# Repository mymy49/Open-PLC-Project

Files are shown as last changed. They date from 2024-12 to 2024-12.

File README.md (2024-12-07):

# Open-PLC-Project
yss OS를 사용한 오픈 소스/회로 PLC 프로젝트입니다.

중국의 [LCSC ELECTRONICS](https://www.lcsc.com/)에서 '전자 부품' + 'PCB' + 'SMT' 주문을 한번에 진행할 수 있는 자료를 모두 오픈할 계획입니다. 
누구나 PCB를 주문해서 거의 완성된 상태로 받아볼 수 있도록 할 계획입니다.
보드의 전체 기능이 yss OS 기반에서 제어 가능한 소스코드를 다운로드하여 필요한 동작을 구현하는 프로젝트입니다.

# 사용 프로그램
* 회로도/PCB : Kicad (<https://www.kicad.org/>)
* Compiler + IDE : gcc + Crossworks for ARM (<https://www.rowley.co.uk/arm/index.htm>)
* Office : Libreoffice (<https://www.libreoffice.org/>)

# Base Board
Base Board는 기본적인 소량의 디지털 I/O, 릴레이, AIN, AOUT을 갖출 계획입니다. 
부족한 기능은 외부에 보드를 추가해 CAN으로 서로 통신하며 기능을 보완하는 것을 계획하고 있습니다.

케이스 : <https://ko.aliexpress.com/item/1005003779239575.html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>

## 단자 구성
케이스는 총 40핀으로 구성되어 있습니다. 
핀맵은 아래와 같이 구성됩니다.

1. [전원] +8~24V (프리볼트)
2. [전원] GND
3. [통신] CANL
4. [통신] CANH

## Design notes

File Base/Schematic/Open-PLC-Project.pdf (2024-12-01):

Open-PLC-Project

페이지 1

# | Reference | Value | Qty | DNP | Manufacturer | 설명

1 | C1,C2 | 0603N120J500 | 2 | | WALSIN | 15pF ±5% 50V NP0
2 | C3 | 0603X475K100 | 1 | | WALSIN | 4.7uF ±10% 10V X5R
3 | C4,C5,C6,C7,C8,C12,C13,C15 | 0603B104K500 | 8 | | WALSIN | 100nF ±10% 50V X7R
4 | C9,C10,C11 | 1210B225K101 | 3 | | WALSIN | 2.2uF ±10% 100V X7R
5 | C14 | 1206B226K100 | 1 | | WALSIN | 22uF ±10% 10V X7R
6 | L1 | SWPA5040S150MT | 1 | | Sunlord | 15uH ±20% 0.086 Ohm 2.0A Isat Shielded
7 | R1 | WR06X1002FTL | 1 | | WALSIN | 10 kOhm 1% 1/10W
8 | R2 | WR06X0000JTL | 1 | DNP | WALSIN | 0 Ohm 5% 1/10W
9 | R3 | WR06X4123FTL | 1 | | WALSIN | 412 kOhm ±1% 1/10W
10 | R4 | WR06X2003FTL | 1 | | WALSIN | 200 kOhm ±1% 1/10W
11 | R5 | WR06X5102FTL | 1 | | WALSIN | 51kOhm ±1% 1/10W
12 | R6 | WR06X2212FTL | 1 | | WALSIN | 22.1kOhm ±1% 1/10W
13 | U1 | STM32F446RET6 | 1 | | ST | ARM Cortex-M4 512kB Flash 128kB RAM 180MHz
14 | U2 | TPS560430XDBV | 1 | | TI | SIMPLE SWITCHER 4V to 36V, 600mA Synchronous Step-Down Converter
15 | U3 | CA-IS3052CW | 1 | | TI | Isolated CAN Transceiver
16 | X1 | 1532H4-12000JWPDTSNL | 1 | | HCI | 12MHz 15pF -40~85℃

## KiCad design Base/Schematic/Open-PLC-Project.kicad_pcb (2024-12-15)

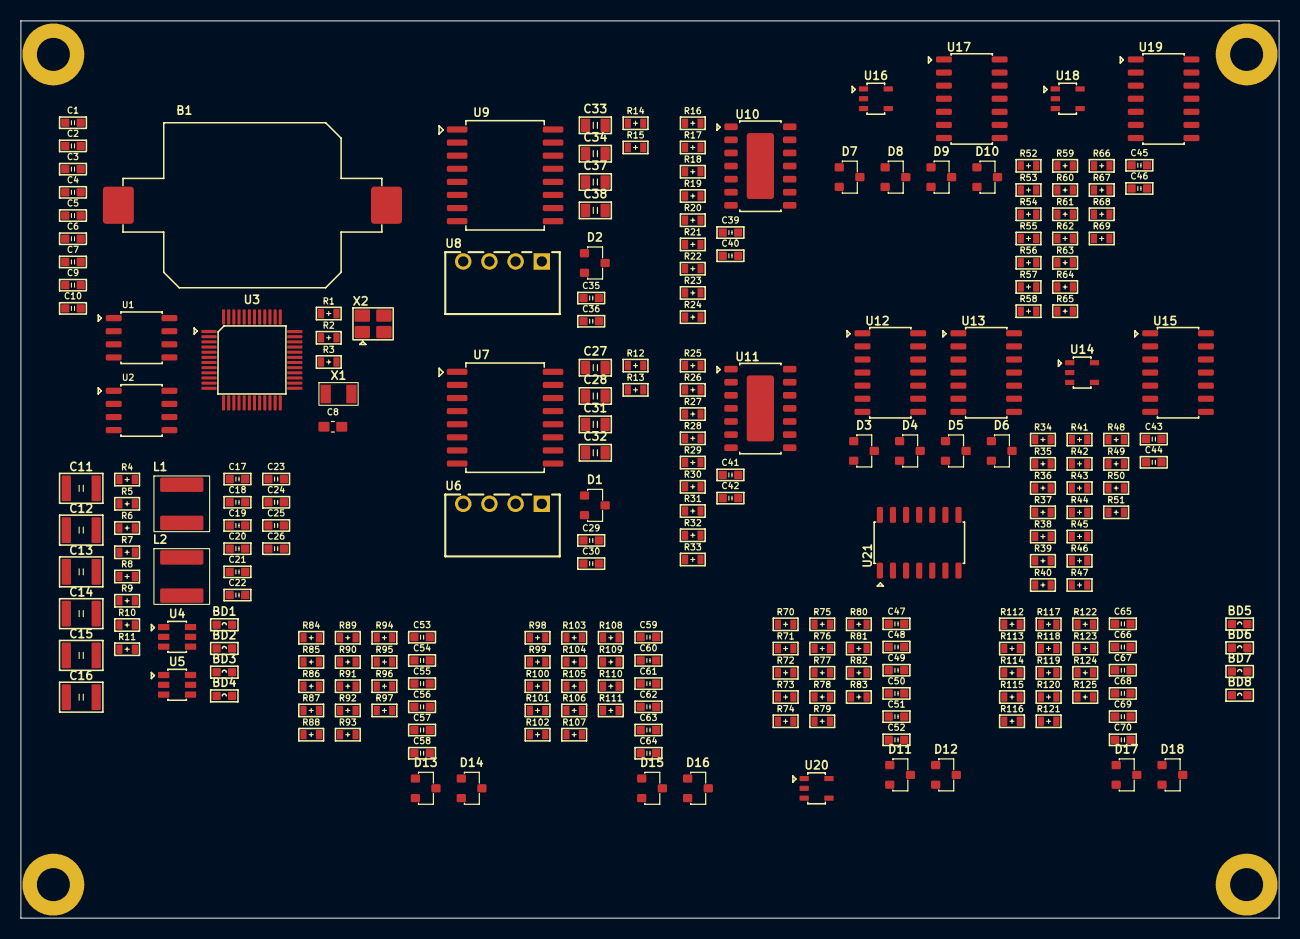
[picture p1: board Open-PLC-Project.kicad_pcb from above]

Board: 2 copper layers, 122.0 x 87.0 mm, 251 parts (0 on the bottom side), 140 nets, no tracks yet.

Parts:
B1: GT-CR1632-1Au
BD1, BD2, BD3, BD4, BD5, BD6, BD7, BD8: BLM18KG121TN1D; 0603
C1, C4, C7, C9, C10, C17, C18, C19, C20, C21, C22, C29, C30, C35, C36, C40, C42, C43, C44, C45, C46, C47, C51, C52, C53, C57, C58, C59, C63, C64, C65, C69, C70: 0603B104K500; 0603
C2, C3, C5, C6: 0603N120J500; 0603
C8: 0603X225K100; C_0603_1608Metric_Pad1.08x0.95mm_HandSolder
C11, C12, C13, C14, C15, C16: 1210B225K101; 1210
C23, C24, C25, C26: 0603X106K100; 0603
C27, C28, C33, C34: 1206B225K500; 0805
C31, C32, C37, C38: 0805B475K160; 0805
C39, C41, C48, C49, C50, C54, C55, C56, C60, C61, C62, C66, C67, C68: 0603B101K500; 0603
D1: NUP2105LT1G; SOT23
D2: PSM712-ES; SOT23
D3, D4, D5, D6, D7, D8, D9, D10, D11, D12, D13, D14, D15, D16, D17, D18: KDS226; SOT23
H1, H2, H3, H4: HOLE-PAD-7.0-3.2; Hole_7_0_3_2
L1, L2: SWPA5040S150MT; SWPA5040S
R1, R2, R23, R32, R34, R36, R37, R38, R39, R40, R41, R42, R43, R44, R45, R46, R47, R52, R54, R55, R56, R57, R58, R59, R60, R61, R62, R63, R64, R65: WR06X4701FTL; 0603
R3: WR06W3R30FTL; 0603
R4, R6: WR06X4123FTL; 0603
R5, R7: WR06X2003FTL; 0603
R8: WR06X8872FTL; 0603
R9, R11: WR06X2212FTL; 0603
R10: WR06X5102FTL; 0603
R12, R13, R14, R15: WR06X0000JTL; 0603
R16, R17, R18, R19, R20, R21, R22, R25, R26, R27, R28, R29, R30, R31, R48, R49, R50, R51, R66, R67, R68, R69, R70, R71, R72, R73, R78, R79, R80, R81, R84, R85, R86, R87, R92, R93, R94, R95, R98, R99, R100, R101, R106, R107, R108, R109, R112, R113, R114, R115, R120, R121, R122, R123: WR06X1002FTL; 0603
R24, R33: WR06X1201FTL; 0603
R35, R53: WR06X4700FTL; 0603
R74, R75, R76, R77, R88, R89, R90, R91, R102, R103, R104, R105, R116, R117, R118, R119: WR06X3302FTL; 0603
R82, R83, R96, R97, R110, R111, R124, R125: WR06X1001FTL; 0603
U1: MB85RC16PNF-G-JNE; SOIC-8
U2: SL1307ZN+T; SOIC-8
U3: M433LE8AE; LQFP48
U4, U5: TPS560430XDBV; DBV0006A
U6, U8: B0505S-1W; BXXS-1W
U7: CA-IS3052CW; SOIC-16-WB
U9: CA-IS3082WX; SOIC-16-WB
U10, U11: BTS5200-4EKA; PG-DSO-14-48-EP
U12, U13: LM239DR2G; SOIC-14
U14, U16, U18, U20: LMV321-TR; SOT-23-5L
U15, U17, U19, U21: TP2584-SR; SOIC-14
X1: XKXGI-SUA-32.768K; SMD_3215_2Pin
X2: 1532H4-12000JWPDTSNL; CRSTAL_SMD_3225-4Pin

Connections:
+3.3V: BD5.2, BD7.2, C1.2, C9.2, C10.2, D11.2 (C1), D12.2 (C1), D13.2 (C1), D14.2 (C1), D15.2 (C1), D16.2 (C1), D17.2 (C1), D18.2 (C1), R1.2, R2.2, R3.2, R44.2, R45.2, R46.2, R47.2, R62.2, R63.2, R64.2, R65.2, U1.8 (VCC), U2.8 (VCC), U3.23 (VDD), U3.39 (VDD), U7.1 (VCC1), U9.1 (VCC1)
+5V: C21.2, C23.2, C25.2, C27.2, C28.2, C29.2, C33.2, C34.2, C35.2, L1.2, R8.1, U6.2 (Vin), U8.2 (Vin)
+5V_485: C36.2, C37.2, C38.2, U8.4 (Vout), U9.16 (VCC2)
+5V_CAN: C30.2, C31.2, C32.2, U6.4 (Vout), U7.16 (VCC2)
/AIN1/AIN_OUT+: C49.1, C51.2, D11.3 (A1C2), R79.2, R82.2
/AIN1/AIN_OUT-: C50.1, C52.2, D12.3 (A1C2), R81.2, R83.2
/AIN1/REF: R78.2, R80.2, U14.3 (-), U14.4 (OUT)
/AIN2/AIN_OUT+: C55.1, C57.2, D13.3 (A1C2), R93.2, R96.2
/AIN2/AIN_OUT-: C56.1, C58.2, D14.3 (A1C2), R95.2, R97.2
/AIN2/REF: R92.2, R94.2, U16.3 (-), U16.4 (OUT)
/AIN3/AIN_OUT+: C61.1, C63.2, D15.3 (A1C2), R107.2, R110.2
/AIN3/AIN_OUT-: C62.1, C64.2, D16.3 (A1C2), R109.2, R111.2
/AIN3/REF: R106.2, R108.2, U18.3 (-), U18.4 (OUT)
/AIN4/AIN_OUT+: C67.1, C69.2, D17.3 (A1C2), R121.2, R124.2
/AIN4/AIN_OUT-: C68.1, C70.2, D18.3 (A1C2), R123.2, R125.2
/AIN4/REF: R120.2, R122.2, U20.3 (-), U20.4 (OUT)
/CAN/CANH: D1.1 (A2), R12.2
/CAN/CANL: D1.2 (C1), R13.2
/DIN1/VREF: C43.2, R34.2, R35.2, U12.6 (-), U13.4 (-), U13.8 (-), U13.10 (-)
/DIN2/VREF: C45.2, R52.2, R53.2, U12.4 (-), U12.8 (-), U12.10 (-), U13.6 (-)
/DOUT1/IS: C39.2, R23.1
/DOUT2/IS: C41.2, R32.1
/MCU/OSC_IN: C5.2, U3.13 (PF3/XT1_IN), X2.1
/MCU/OSC_OUT: C6.2, U3.14 (PF2/XT1_OUT), X2.3
/MCU/SCL: R2.1, U1.6 (SCL), U2.6 (SCL)
/MCU/SDA: R1.1, U1.5 (SDA), U2.5 (SDA)
/MCU/X1: C3.2, U2.1 (X1), X1.2
/MCU/X2: C2.2, U2.2 (X2), X1.1
/RS485/A: D2.1 (A2), R14.2
/RS485/B: D2.2 (C1), R15.2
AGND: BD4.2, BD6.1, C47.1, C51.1, C52.1, C53.1, C57.1, C58.1, C59.1, C63.1, C64.1, C65.1, C69.1, C70.1, D11.1 (A2), D12.1 (A2), D13.1 (A2), D14.1 (A2), D15.1 (A2), D16.1 (A2), D17.1 (A2), D18.1 (A2), R71.2, R85.2, R99.2, R113.2, U3.46 (AVSS), U14.2 (VSS), U15.11 (GND), U16.2 (VSS), U17.11 (GND), U18.2 (VSS), U19.11 (GND), U20.2 (VSS), U21.11 (GND)
A_+3.3V: BD5.1, R70.1, R84.1, R98.1, R112.1, U14.5 (VDD), U16.5 (VDD), U18.5 (VDD), U20.5 (VDD)
A_V_SUPPLY: BD3.2, U15.4 (VCC), U17.4 (VCC), U19.4 (VCC), U21.4 (VCC)
GND: B1.2 (-), BD6.2, BD8.2, C1.1, C2.1, C3.1, C4.1, C5.1, C6.1, C7.1, C8.1, C9.1, C10.1, C39.1, C41.1, U1.4 (VSS), U2.4 (VSS), U3.37 (VSS), U7.2 (GND1), U7.8 (GND1), U9.2 (GND1), U9.7 (GND1), U9.8 (GND1)
GND_485: C36.1, C37.1, C38.1, U8.3 (0V), U9.9 (GND2), U9.10 (GND2), U9.15 (GND2)
GND_CAN: C30.1, C31.1, C32.1, D1.3 (A1C2), D2.3 (A1C2), U6.3 (0V), U7.9 (GND2), U7.10 (GND2), U7.15 (GND2)
unnamed: B1.1 (+), C4.2, U2.3 (VBAT)
unnamed: BD7.1, C22.2, C24.2, C26.2, L2.2, R10.2
unnamed: D3.3 (A1C2), R36.2, R40.1
unnamed: D4.3 (A1C2), R37.2, R41.1
unnamed: D5.3 (A1C2), R38.2, R42.1
unnamed: D6.3 (A1C2), R39.2, R43.1
unnamed: D7.3 (A1C2), R54.2, R58.1
unnamed: D8.3 (A1C2), R55.2, R59.1
unnamed: D9.3 (A1C2), R56.2, R60.1
unnamed: D10.3 (A1C2), R57.2, R61.1
unnamed: C7.2, R3.1, U3.45 (AVDD)
unnamed: C8.2, U3.38 (LDO_CAP)
unnamed: C19.2, U4.1 (CB)
unnamed: R4.1, R5.2, U4.4 (EN)
unnamed: R8.2, R9.2, U4.3 (FB)
unnamed: C19.1, L1.1, U4.6 (SW)
unnamed: BD1.2, C11.2, C13.2, C15.2, C17.2, R4.2, U4.5 (VIN)
unnamed: C20.2, U5.1 (CB)
unnamed: R6.1, R7.2, U5.4 (EN)
unnamed: R10.1, R11.2, U5.3 (FB)
unnamed: C20.1, L2.1, U5.6 (SW)
unnamed: BD2.2, C12.2, C14.2, C16.2, C18.2, R6.2, U5.5 (VIN)
unnamed: R12.1, U7.13 (CANH)
unnamed: R13.1, U7.12 (CANL)
unnamed: R14.1, U9.12 (A)
unnamed: R15.1, U9.13 (B)
unnamed: R20.2, U10.10 (DEN)
unnamed: R21.2, U10.5 (DSEL0)
unnamed: R22.2, U10.4 (DSEL1)
unnamed: R16.2, U10.7 (IN0)
unnamed: R17.2, U10.6 (IN1)
unnamed: R18.2, U10.8 (IN2)
unnamed: R19.2, U10.9 (IN3)
unnamed: R23.2, R24.2, U10.12 (IS)
unnamed: R29.2, U11.10 (DEN)
unnamed: R30.2, U11.5 (DSEL0)
unnamed: R31.2, U11.4 (DSEL1)
unnamed: R25.2, U11.7 (IN0)
unnamed: R26.2, U11.6 (IN1)
unnamed: R27.2, U11.8 (IN2)
unnamed: R28.2, U11.9 (IN3)
unnamed: R32.2, R33.2, U11.12 (IS)
unnamed: R40.2, U12.7 (+)
unnamed: R44.1, R48.1, U12.1 (OUT)
unnamed: R59.2, U12.5 (+)
unnamed: R63.1, R67.1, U12.2 (OUT)
unnamed: R60.2, U12.9 (+)
unnamed: R64.1, R68.1, U12.14 (OUT)
unnamed: R61.2, U12.11 (+)
unnamed: R65.1, R69.1, U12.13 (OUT)
unnamed: R58.2, U13.7 (+)
unnamed: R62.1, R66.1, U13.1 (OUT)
unnamed: R41.2, U13.5 (+)
unnamed: R45.1, R49.1, U13.2 (OUT)
unnamed: R42.2, U13.9 (+)
unnamed: R46.1, R50.1, U13.14 (OUT)
unnamed: R43.2, U13.11 (+)
unnamed: R47.1, R51.1, U13.13 (OUT)
unnamed: C47.2, R70.2, R71.1, U14.1 (+)
unnamed: C48.1, R72.2, U15.3 (+)
unnamed: R74.1, R77.1, U15.1 (OUT), U15.2 (-)
unnamed: C48.2, R73.2, U15.5 (+)
unnamed: R75.1, R76.1, U15.6 (-), U15.7 (OUT)
unnamed: R74.2, R78.1, U15.10 (+)
unnamed: C49.2, R75.2, R79.1, U15.9 (-)
unnamed: R82.1, U15.8 (OUT)
unnamed: R76.2, R80.1, U15.12 (+)
unnamed: C50.2, R77.2, R81.1, U15.13 (-)
unnamed: R83.1, U15.14 (OUT)
unnamed: C53.2, R84.2, R85.1, U16.1 (+)
unnamed: C54.1, R86.2, U17.3 (+)
unnamed: R88.1, R91.1, U17.1 (OUT), U17.2 (-)
unnamed: C54.2, R87.2, U17.5 (+)
unnamed: R89.1, R90.1, U17.6 (-), U17.7 (OUT)
unnamed: R88.2, R92.1, U17.10 (+)
unnamed: C55.2, R89.2, R93.1, U17.9 (-)
unnamed: R96.1, U17.8 (OUT)
unnamed: R90.2, R94.1, U17.12 (+)
unnamed: C56.2, R91.2, R95.1, U17.13 (-)
unnamed: R97.1, U17.14 (OUT)
unnamed: C59.2, R98.2, R99.1, U18.1 (+)
unnamed: C60.1, R100.2, U19.3 (+)
unnamed: R102.1, R105.1, U19.1 (OUT), U19.2 (-)
unnamed: C60.2, R101.2, U19.5 (+)
unnamed: R103.1, R104.1, U19.6 (-), U19.7 (OUT)
unnamed: R102.2, R106.1, U19.10 (+)
unnamed: C61.2, R103.2, R107.1, U19.9 (-)
unnamed: R110.1, U19.8 (OUT)
unnamed: R104.2, R108.1, U19.12 (+)
unnamed: C62.2, R105.2, R109.1, U19.13 (-)
unnamed: R111.1, U19.14 (OUT)
unnamed: C65.2, R112.2, R113.1, U20.1 (+)
unnamed: C66.1, R114.2, U21.3 (+)
unnamed: R116.1, R119.1, U21.1 (OUT), U21.2 (-)
unnamed: C66.2, R115.2, U21.5 (+)
unnamed: R117.1, R118.1, U21.6 (-), U21.7 (OUT)
unnamed: R116.2, R120.1, U21.10 (+)
unnamed: C67.2, R117.2, R121.1, U21.9 (-)
unnamed: R124.1, U21.8 (OUT)
unnamed: R118.2, R122.1, U21.12 (+)
unnamed: C68.2, R119.2, R123.1, U21.13 (-)
unnamed: R125.1, U21.14 (OUT)
PGND: BD4.1, BD8.1, C11.1, C12.1, C13.1, C14.1, C15.1, C16.1, C17.1, C18.1, C21.1, C22.1, C23.1, C24.1, C25.1, C26.1, C27.1, C28.1, C29.1, C33.1, C34.1, C35.1, C40.1, C42.1, C43.1, C44.1, C45.1, C46.1, D3.1 (A2), D4.1 (A2), D5.1 (A2), D6.1 (A2), D7.1 (A2), D8.1 (A2), D9.1 (A2), D10.1 (A2), R5.1, R7.1, R9.1, R11.1, R24.1, R33.1, R35.1, R53.1, U4.2 (GND), U5.2 (GND), U6.1 (GND), U8.1 (GND), U10.11 (GND), U11.11 (GND), U12.12 (GND), U13.12 (GND)
V_SUPPLY: BD1.1, BD2.1, BD3.1, C40.2, C42.2, C44.2, C46.2, D3.2 (C1), D4.2 (C1), D5.2 (C1), D6.2 (C1), D7.2 (C1), D8.2 (C1), D9.2 (C1), D10.2 (C1), R34.1, R52.1, U10.EP (VS), U11.EP (VS), U12.3 (VCC), U13.3 (VCC)

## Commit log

2024-12-01 [회로도 등록] - 테스트를 위해 MCU 하나만 올린 회로도면을 추가함
    [Open-PLC-Project.kicad_pcb, Open-PLC-Project.kicad_sch]
2024-12-01 [폴더 구조 변경] - 회로도 일부 업데이트
    [MCU.kicad_sch, Open-PLC-Project.kicad_pcb, Open-PLC-Project.kicad_sch]
2024-12-01 [소스 코드 추가]
2024-12-01 [Base 회로 업데이트] - 전원 회로 추가
    [MCU.kicad_sch, Open-PLC-Project.kicad_sch, Power.kicad_sch]
2024-12-01 [BOM 문서 테스트] - Libreoffice로 BOM 문서 출력 테스트 - 회로도에 CAN transceiver 추가
    [CAN.kicad_sch, Open-PLC-Project.csv, Open-PLC-Project.kicad_sch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]
2024-12-03 [Base 회로도 업데이트] - MCU를 STM32F446 -> Nuvoton M433으로 변경
    [MCU.kicad_sch]
2024-12-07 [Base 횔로도 업데이트] - CAN 통신용 5V 절연된 전원 추가
    [CAN.kicad_sch]
2024-12-07 [Base 회로도 업데이트] - 5V 전원 추가 - 3.3V, 5V 회로도 보완
    [Power.kicad_sch]
2024-12-07 [Base 회로도 업데이트] - RTC 회로 추가 - M433에는 VBAT 단자가 없어서 별도 부품으로 추가함
    [MCU.kicad_sch]
2024-12-07 Update README.md
    - 소개 내용 추가
    - 사용 프로그램 추가
    - Base 보드에 관한 소개
    - 단자 구성 일부 추가
2024-12-07 Update README.md
    - LCSC 표기 변경 및 링크 추가
2024-12-14 [Base 회로도 업데이트] - RS485 회로 추가
    [Open-PLC-Project.kicad_sch, RS485.kicad_sch]
2024-12-14 [Base 회로도 업데이트] - RS485, CAN 보호회로 추가
    [CAN.kicad_sch, RS485.kicad_sch]
2024-12-14 [Base 회로도 업데이트] - DOUT 회로 추가
    [DOUT.kicad_sch, Open-PLC-Project.kicad_sch]
2024-12-14 [Base 회로도 업데이트] - DOUT 출력을 4개에서 8개로 늘림
    [DOUT.kicad_sch, Open-PLC-Project.kicad_sch]
2024-12-14 [Base PCB 업데이트] - PCB 외곽선과 볼트 위치 설정
    [CAN.kicad_sch, DOUT.kicad_sch, MCU.kicad_sch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]
2024-12-14 [Base 회로도 업데이트] - DIN 입력 8개 추가
    [DIN.kicad_sch, Open-PLC-Project.kicad_sch]
2024-12-15 [Base 회로도 업데이트] - AIN 입력 4개 추가
    [AIN.kicad_sch, CAN.kicad_sch, DIN.kicad_sch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]

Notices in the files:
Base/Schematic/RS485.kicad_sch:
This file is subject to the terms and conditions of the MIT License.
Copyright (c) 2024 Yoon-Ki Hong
